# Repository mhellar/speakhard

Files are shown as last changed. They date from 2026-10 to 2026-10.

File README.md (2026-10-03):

# SPEAK//HARD

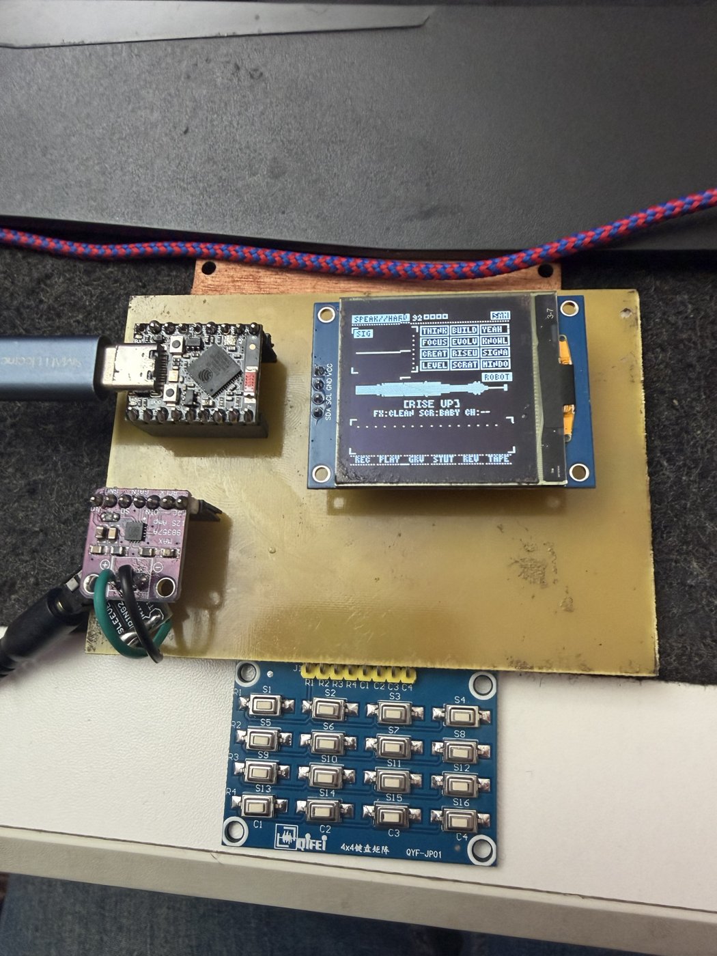
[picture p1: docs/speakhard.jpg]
SPEAK//HARD board


A handheld speech beat machine on an ESP32-S3. Four instruments (SAM voice, Talkie LPC voice, bytebeat, a 12-piece drum kit) on a 16-step sequencer, seven voice FX plus stutter/reverse/tape-stop/scratch, and a live HUD on a 128x128 OLED.

Co-created by Mark Hellar and Claude (Anthropic AI): hardware, design and sound direction by Mark; firmware and PCB layout co-written with Claude. PCB milled and soldered by Mark Hellar.

## Hardware

| Part | Notes |
|---|---|
| ESP32-S3 SuperMini | 4 MB flash, 2 MB PSRAM (PSRAM is required) |
| 1.5" SH1107 128x128 I2C OLED | header order VCC GND SCL SDA |
| MAX98357A I2S amp breakout + small speaker | VIN from 5V |
| 4x4 tact keypad module (QYF-JP01) | passive matrix, mounts on edge pads off the bottom edge |
| Pot module (optional) | edge pads on the right edge; not used by this firmware |

### Pins

| Function | GPIO |
|---|---|
| OLED SDA / SCL | 9 / 8 |
| Keypad rows R1-R4 | 2, 3, 4, 5 |
| Keypad columns C1-C4 | 6, 7, 13, 12 |
| Amp LRC / BCLK / DIN | 1 / 44 / 43 |
| Pot wiper / pot high leg (driven HIGH) | 10 / 11 |

### PCB

Single-sided, all copper on B.Cu, designed for CNC isolation milling on a 100 x 70 mm copper-clad blank. Modules plug into female headers; the keypad and pot modules lie on SMD edge pads with their right-angle pins.

- `hardware/` KiCad 10 project (schematic, PCB, symbol library, `ks_cnc.pretty` footprints)
- `hardware/cnc/` Gerbers (B.Cu, Edge.Cuts), PTH/NPTH drills, a 1:1 fit-test PDF, and ready-made GRBL G-code:
  `1_isolation_0.1vbit.nc` (0.1 mm 20 deg V-bit, Z -0.05) -> `2_holes_1.0drill.nc` -> `3_mounting_2.0drill.nc` -> `4_outline_score_0.1vbit.nc`.
  `load_and_mirror.tcl` regenerates the G-code in FlatCAM (mirrored, since the copper is on the bottom);
  `fix_drill_spinup.py` patches drill files for GRBL laser mode. See `CNC_CHEATSHEET.txt`.

Print `PRINT_1to1_fit_test.pdf` and check your modules against it before milling: the OLED, keypad and pot outlines were measured from photos and typical specs.

## Firmware

`firmware/speakbeat_hard/` is the instrument. `firmware/keypad_bringup/` is a quick test (keys play notes, OLED grid).

Build with the Arduino IDE or arduino-cli:

- ESP32 Arduino core 3.x (tested on 3.3.5)
- Board: ESP32S3 Dev Module, USB CDC On Boot: Enabled, PSRAM: enabled
- Library: U8g2. esp-dsp ships with the ESP32 core.

```
arduino-cli compile --fqbn "esp32:esp32:esp32s3:CDCOnBoot=cdc,PSRAM=enabled" firmware/speakbeat_hard
arduino-cli upload  --fqbn "esp32:esp32:esp32s3:CDCOnBoot=cdc,PSRAM=enabled" -p <port> firmware/speakbeat_hard
```

If the board sits silent after an upload, press RST: on the SuperMini the auto-reset can leave it in the bootloader.

Audio runs at 22.05 kHz in a task on core 0 (it also scans the keypad); the display loop runs on core 1.

## Controls

The left keypad column holds the modifiers; the other 12 keys are pads.

```
[MODE ] [ pad 0 ] [ pad 1 ] [ pad 2 ]
[FX   ] [ pad 3 ] [ pad 4 ] [ pad 5 ]
[SEQ  ] [ pad 6 ] [ pad 7 ] [ pad 8 ]
[SHIFT] [ pad 9 ] [ pad 10] [ pad 11]
```

Tap a modifier for its quick action. Hold it and the screen shows what the 12 pads do while it's held.

| Modifier | Tap | Hold + pad 0..11 |
|---|---|---|
| MODE | next mode | SAM, TALK, BYTE, DRUM, VOL-, VOL+, BANK, voices ROBOT / SAM / ELF / E.T. / BRUTE |
| FX | next FX | CLEAN, CRUSH, ECHO, GRAIN, SWARM, VOX, MEGA, then momentary STUTTER, REVERSE, TAPE, UNDER, and scratch style |
| SEQ | REC on/off | REC, PLAY, GROOVE, AUTO, BPM-, BPM+, MUTATE, CHORDS, CLR VOX, CLR DRM, CLR BYT, CLR ALL |
| SHIFT | PLAY/STOP | per mode, see below |

| Mode | Pads | SHIFT + pad |
|---|---|---|
| SAM | 12 words; tap = say, hold = scratch | scratch the word |
| TALK | 12 LPC words, 4 banks (LIFTOFF, SKY, MATH, PHONETIC); tap = say, hold = scrub the frames | WHISPER, MONO, FREEZE, STRETCH, PITCH-, PITCH+, PITCH 0, GLITCH, BACKWARD, FORMANT-, FORMANT+, RESET |
| BYTE | 12 bytebeat formulas; tap = latch, hold = momentary | RATE/2, RATE*2, A-, A+, B-, B+, SYNC, STOP, CRUSH, REVERSE, RANDOM, RESET |
| DRUM | KICK SNARE CLAP HAT / OPEN 808 ANVIL PIPE / SLAM ZAP CRASH CHUG; tap = hit, hold = roll | mute that drum |

With REC on, everything you play is quantized into the 16 steps. It boots stopped with an empty pattern.

### Sound engine

- SAM words are pre-rendered into PSRAM, so they can be scratched, stuttered and granulated.
- Talkie words are decoded to LPC frames at boot and resynthesized live through the 10-pole lattice filter, so pitch, formant, voicing and coefficients can be bent while it talks.
- VOX is a 16-band vocoder (esp-dsp biquads) with SAM as the modulator and a driven polyBLEP chord carrier. Chord sets: DROP, DREAD, EPIC, MACHINE.
- Drums are synthesized: driven sine kick with a click, metal snare, multi-burst clap, 808-style hats from six detuned square waves, FM clangs, and CHUG, a fuzz power chord that follows the chord progression.
- Kick, 808 and SLAM duck the voices; a soft compressor and a 40 Hz highpass sit on the master.
- `tools/drumsim.py` is a Python port of the drum engine that prints each hit's level; run it after changing the `PERC[]` table.

## Credits

- **SAM** (Software Automatic Mouth, Don't Ask Software, 1982). C port by Sebastian Macke; ESP8266SAM by Earle Philhower.
- **Talkie** by Peter Knight; vocabularies converted by Armin Joachimsmeyer. LPC tables and lattice filter via ESP8266Audio's AudioGeneratorTalkie.
- **esp-dsp** by Espressif.
- **U8g2** by olikraus.
- **Bytebeat** formulas from the viznut (2011) bytebeat scene.

Details in [THIRD_PARTY.md](THIRD_PARTY.md).

## License

GPL v3. See [LICENSE](LICENSE).

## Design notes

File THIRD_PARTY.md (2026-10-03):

# Third-party code

Bundled in `firmware/speakbeat_hard/`:

| Files | Origin | License as stated by the source |
|---|---|---|
| `sam.c`, `render.c`, `reciter.c`, `*Tabs.h`, `SamData.h`, `sam.h`, `render.h`, `reciter.h`, `esp8266sam_debug.*` | SAM, Software Automatic Mouth (Don't Ask Software, 1982), C port by Sebastian Macke (github.com/s-macke/SAM), ESP8266 adaptation by Earle F. Philhower III (github.com/earlephilhower/ESP8266SAM) | ESP8266SAM is distributed under GPL v3. The original 1982 SAM is old commercial software whose copyright status the C port's author describes as unclear. |
| `Vocab_US_Large.*`, `Vocab_AstroBlaster.*`, `Vocab_Soundbites.*`, `Vocab_Toms_Diner.*` | Talkie by Peter Knight (2011), vocabularies converted to .c/.h by Armin Joachimsmeyer (github.com/ArminJo/Talkie) | File headers say "released under GPLv2 license" |
| LPC tables and lattice filter inside `speakbeat_hard.ino` | Talkie by Peter Knight, via ESP8266Audio's AudioGeneratorTalkie (github.com/earlephilhower/ESP8266Audio) | GPL v3 (ESP8266Audio) |

Used as libraries, not bundled:

| Library | Author | License |
|---|---|---|
| U8g2 | olikraus | 2-clause BSD |
| esp-dsp | Espressif | Apache 2.0 |
| arduino-esp32 core (ESP_I2S, Wire) | Espressif | LGPL 2.1 |

The bytebeat formulas are well-known one-liners from the bytebeat scene started by viznut in 2011.

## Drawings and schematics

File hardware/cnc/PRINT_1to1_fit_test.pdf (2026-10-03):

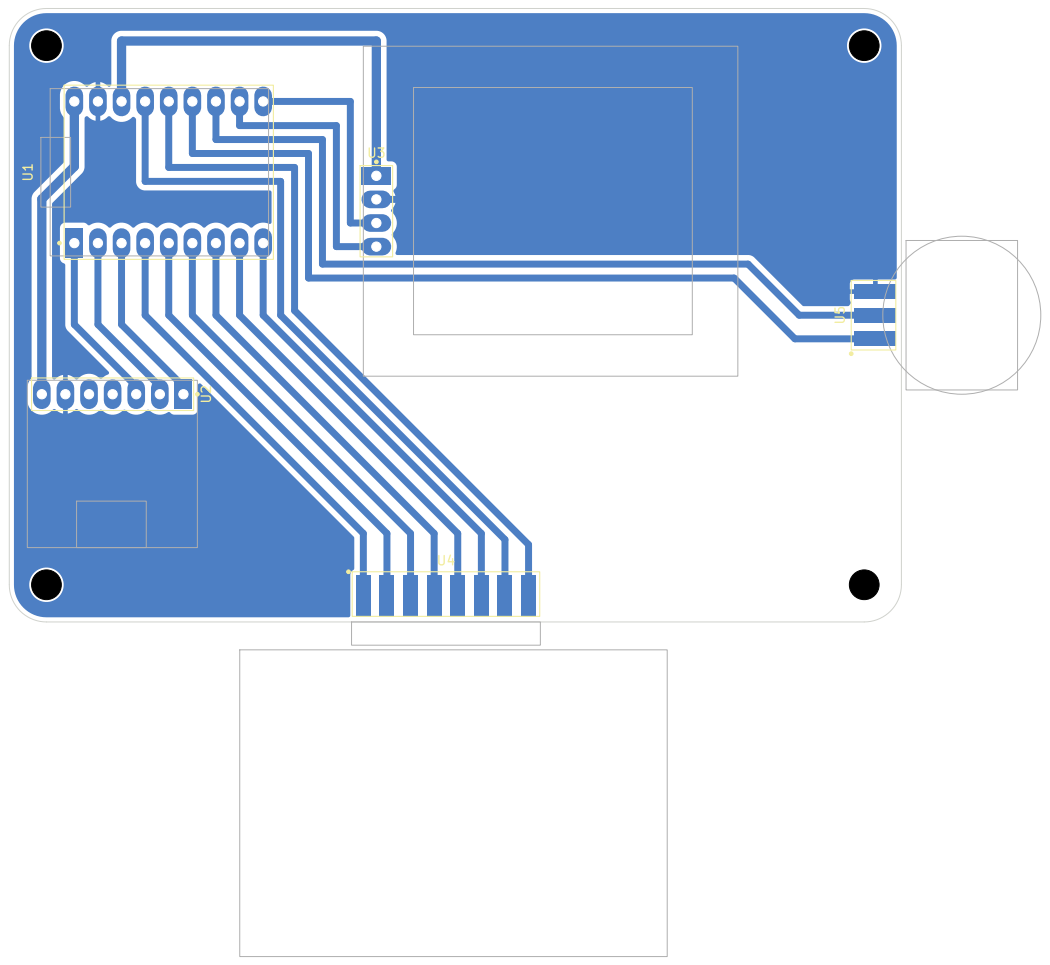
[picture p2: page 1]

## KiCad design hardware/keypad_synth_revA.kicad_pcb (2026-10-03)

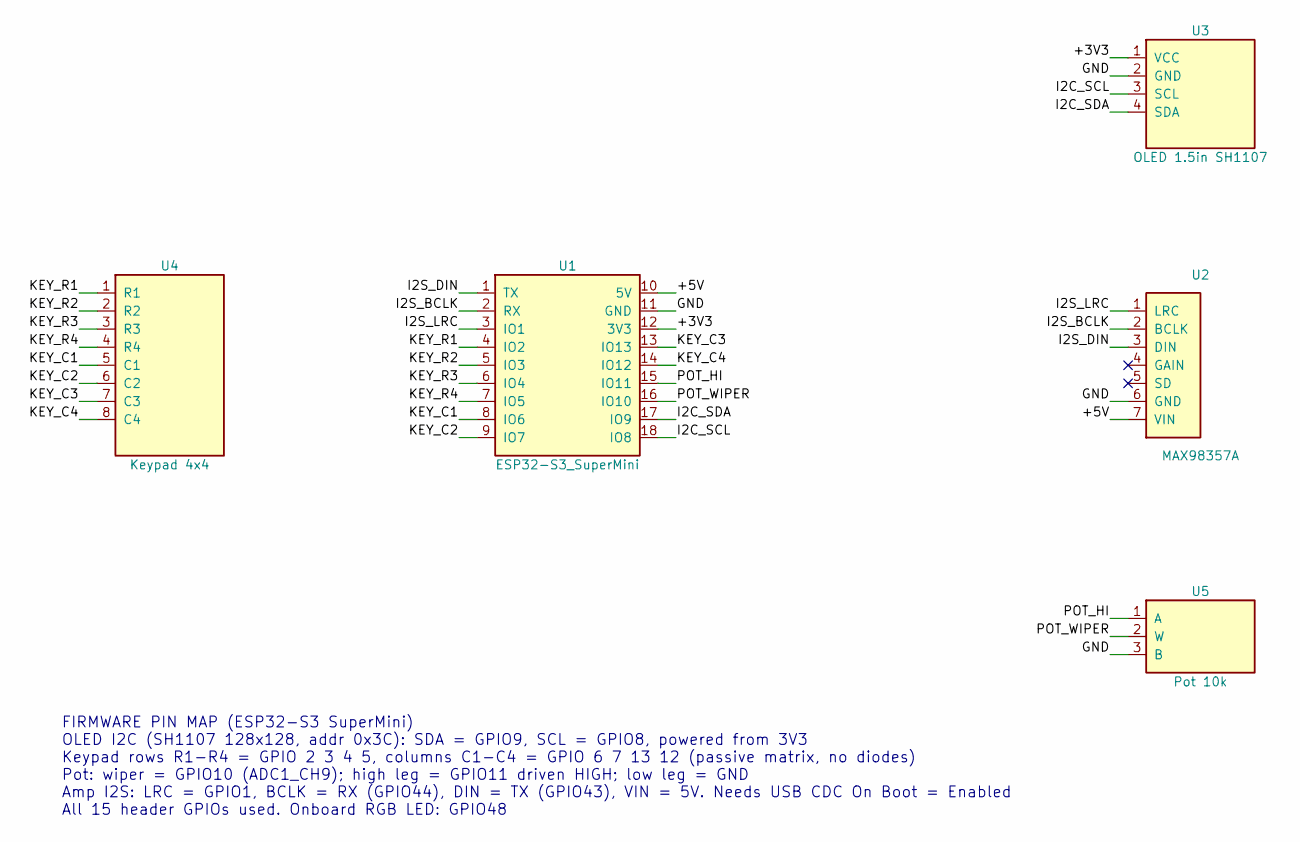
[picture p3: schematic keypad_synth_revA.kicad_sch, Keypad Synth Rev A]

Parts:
U1: ESP32-S3_SuperMini; ESP32-S3_SuperMini_CNC
U2: MAX98357A; MAX98357A_Module_CNC
U3: OLED 1.5in SH1107; OLED_1.5in_128x128_I2C_CNC
U4: Keypad 4x4; EdgePads_Keypad4x4_CNC
U5: Pot 10k; EdgePads_Pot_CNC

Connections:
/+3V3: U1.12 (3V3), U3.1 (VCC)
/+5V: U1.10 (5V), U2.7 (VIN)
/GND: U1.11 (GND), U2.6 (GND), U3.2 (GND), U5.3 (B)
/I2C_SCL: U1.18 (IO8), U3.3 (SCL)
/I2C_SDA: U1.17 (IO9), U3.4 (SDA)
/I2S_BCLK: U1.2 (RX), U2.2 (BCLK)
/I2S_DIN: U1.1 (TX), U2.3 (DIN)
/I2S_LRC: U1.3 (IO1), U2.1 (LRC)
/KEY_C1: U1.8 (IO6), U4.5 (C1)
/KEY_C2: U1.9 (IO7), U4.6 (C2)
/KEY_C3: U1.13 (IO13), U4.7 (C3)
/KEY_C4: U1.14 (IO12), U4.8 (C4)
/KEY_R1: U1.4 (IO2), U4.1 (R1)
/KEY_R2: U1.5 (IO3), U4.2 (R2)
/KEY_R3: U1.6 (IO4), U4.3 (R3)
/KEY_R4: U1.7 (IO5), U4.4 (R4)
/POT_HI: U1.15 (IO11), U5.1 (A)
/POT_WIPER: U1.16 (IO10), U5.2 (W)

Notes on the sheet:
FIRMWARE PIN MAP (ESP32-S3 SuperMini) OLED I2C (SH1107 128x128, addr 0x3C): SDA = GPIO9, SCL = GPIO8, powered from 3V3 Keypad rows R1-R4 = GPIO 2 3 4 5, columns C1-C4 = GPIO 6 7 13 12 (passive matrix, no diodes) Pot: wiper = GPIO10 (ADC1_CH9); high leg = GPIO11 driven HIGH; low leg = GND Amp I2S: L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

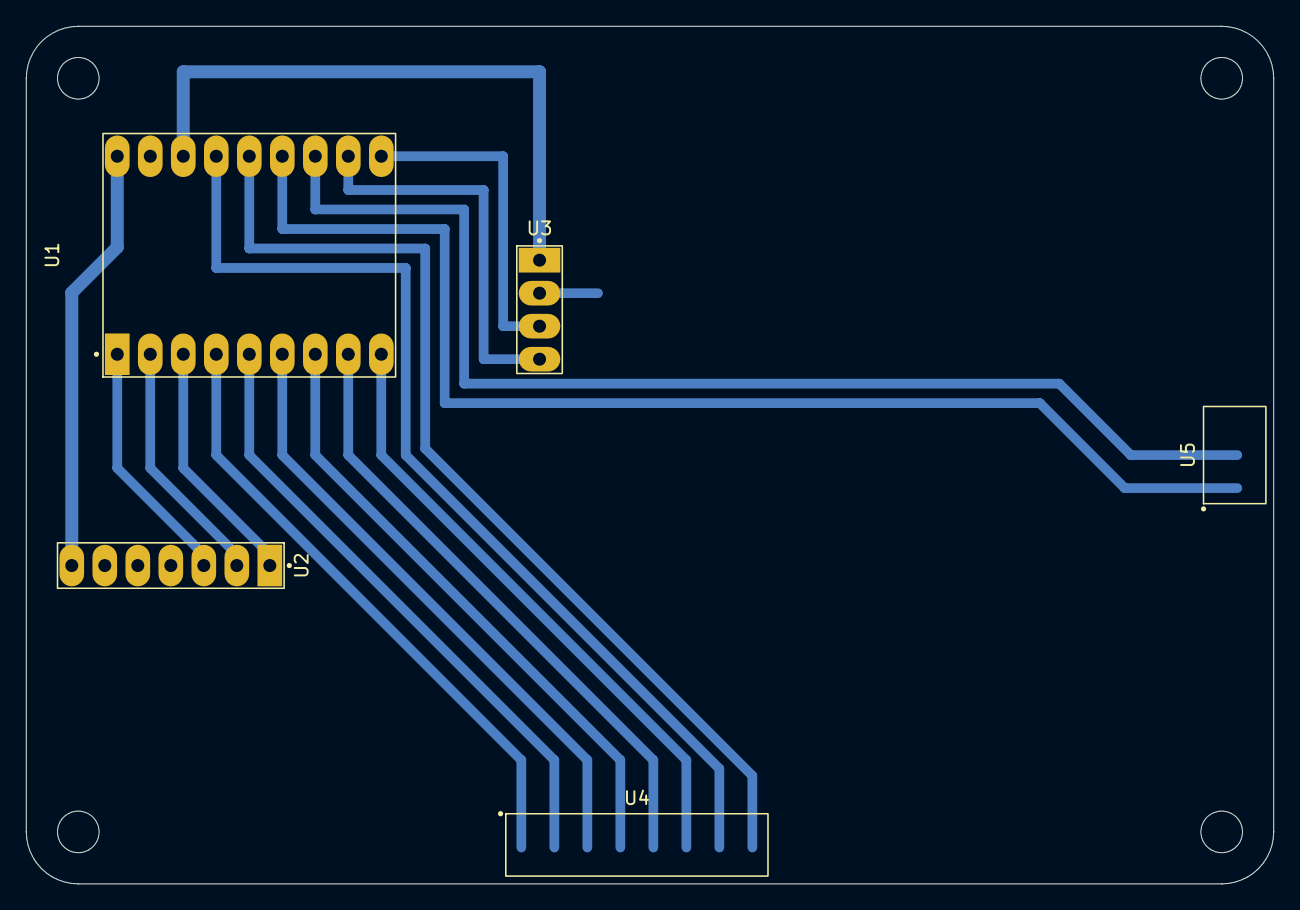
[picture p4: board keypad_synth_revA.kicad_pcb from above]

Board: 2 copper layers, 96.0 x 66.0 mm, 9 parts (0 on the bottom side), 18 nets.

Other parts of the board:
H1, H2, H3, H4: MountingHole_3.2mm_M3

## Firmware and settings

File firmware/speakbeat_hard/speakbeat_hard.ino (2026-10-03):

/*
  SPEAK//HARD - the industrial fork of SPEAK//BEAT (keypad_synth_revA)
  ===========================================================================================================
  Same instrument, harder body: industrial drum kit (driven kick, metal snare, 808-style metal hats, ANVIL/PIPE
  FM clangs, SLAM, 808 sub) plus CHUG, a palm-muted drop-tuned power-chord stab on drum pad 11 that follows the
  chord progression. Kick/808/slam duck the voices (sidechain pump), a soft glue compressor sits on the master,
  MEGA (megaphone voice) replaces CHOIR, the vocoder carrier is driven, progressions are DROP/DREAD/EPIC/MACHINE,
  the BRUTE voice replaces OLD LADY, and the default is 92 BPM. The original speakbeat sketch is untouched.

  Grown out of handheld_robodj (the deck, scratching, voice FX, vocoder and sequencer come from there).
  SAM (Software Automatic Mouth, C core from earlephilhower/ESP8266SAM) and the Talkie LPC vocabularies
  (Peter Knight / Armin Joachimsmeyer) are bundled in this folder; both GPL v3, so this sketch is too.

  KEYPAD (keypad hanging below the board, S1 top-left)
     [MODE ] [ pad 0 ] [ pad 1 ] [ pad 2 ]
     [FX   ] [ pad 3 ] [ pad 4 ] [ pad 5 ]
     [SEQ  ] [ pad 6 ] [ pad 7 ] [ pad 8 ]
     [SHIFT] [ pad 9 ] [ pad 10] [ pad 11]
  Left column: tap for the quick action, HOLD it and the screen shows what the 12 pads do.
     MODE  tap = next mode (SAM > TALK > BYTE > DRUM)      hold: modes, volume, talk bank, SAM voice
     FX    tap = next voice FX                              hold: pick FX, momentary STUTTER/REVERSE/TAPE/UNDER
     SEQ   tap = REC on/off                                 hold: play/stop, groove, auto, BPM, mutate, clears
     SHIFT tap = PLAY/STOP                                  hold: per-mode extras (scratch, LPC bends, bytebeat
                                                                  params, drum mutes)
  Pads by mode:
     SAM   12 positive words. tap = say it, hold = scratch it
     TALK  12 Speak & Spell / arcade LPC words (3 banks). tap = say it, hold = scrub-scratch the LPC frames
     BYTE  12 bytebeat formulas. tap = start/stop (latched), hold = plays only while held
     DRUM  12 drums (KICK SNARE CLAP HAT / OPEN 808 ANVIL PIPE / SLAM ZAP CRASH CHUG). tap = hit, hold = roll
  With REC on, everything you play is quantized into the 16 steps.

  Board: "ESP32S3 Dev Module", USB CDC On Boot: Enabled, PSRAM: enabled
  (arduino-cli FQBN esp32:esp32:esp32s3:CDCOnBoot=cdc,PSRAM=enabled). Libraries: U8g2. ESP32 core 3.x.
*/

#include <Arduino.h>
#include <Wire.h>
#include <U8g2lib.h>
#include <ESP_I2S.h>
#include "esp_dsp.h"
#include "SamData.h"
#include "sam.h"
#include "reciter.h"
#include "Vocab_US_Large.h"
#include "Vocab_AstroBlaster.h"
#include "Vocab_Soundbites.h"
#include "Vocab_Toms_Diner.h"

// ---------------- pins (keypad_synth_revA netlist) ----------------
#define PIN_SDA   9
#define PIN_SCL   8
#define AMP_LRC   1
#define AMP_BCLK  44
#define AMP_DIN   43
#define PIN_RGB   48
const int ROW_PINS[4] = {2, 3, 4, 5};
const int COL_PINS[4] = {6, 7, 13, 12};

#define STATUS_LOG 0      // 1 = print a status line every 2 s (only needed for debugging)
#define FS     22050
#define INV_FS (1.0f / FS)
#define BLOCK  128

const float VOLS[6] = {0.05f, 0.09f, 0.14f, 0.2f, 0.28f, 0.38f};
volatile int volIdx = 2;

// ---------------- types first (Arduino auto-prototypes) ----------------
struct Word { const char* text; uint32_t off, len; };
struct Voice { const char* name; uint8_t speed, pitch, throat, mouth; };
struct Step { int8_t word; uint8_t src, flags; int8_t byteF; uint16_t drum; bool skip; };
struct LpcFrame { uint8_t energy, period; int16_t k1, k2; int8_t k[8]; };
struct TalkWord { const char* name; const uint8_t* data; uint32_t first, n; };
struct PercDef { const char* name; uint8_t wave; float f0, f1, ptime, dec, gain, noise, drive; };
struct ModKey { bool down, used; uint32_t tDown; };

enum { M_SAM, M_TALK, M_BYTE, M_DRUM, M_COUNT };
const char* MODE_NAMES[] = {"SAM", "TALK", "BYTE", "DRUM"};
enum { K_MODE, K_FX, K_SEQ, K_SHIFT };
const char* MOD_NAMES[] = {"MODE", "FX", "SEQ", "SHIFT"};
enum { SRC_SAM, SRC_TALK };
enum { SF_SCRATCH = 1, SF_REV = 2 };
enum { FX_CLEAN, FX_CRUSH, FX_ECHO, FX_GRAIN, FX_SWARM, FX_VOX, FX_MEGA, FX_COUNT };
const char* FX_NAMES[] = {"CLEAN", "CRUSH", "ECHO", "GRAIN", "SWARM", "VOX", "MEGA"};
enum { SC_BABY, SC_CHIRP, SC_TRANS, SC_TEAR, SC_FLARE, SC_COUNT };
const char* SC_NAMES[] = {"BABY", "CHIRP", "TRANSFM", "TEAR", "FLARE"};
#define BYTE_STOP 99

const Voice VOICES[] = {
  {"ROBOT", 92, 60, 190, 190}, {"SAM", 72, 64, 128, 128}, {"ELF", 72, 64, 110, 160},
  {"E.T.", 100, 64, 150, 200}, {"BRUTE", 84, 104, 100, 150},
};
// poetic, positive, short enough to hit like a drum (the last one is the long line to chop up)
Word bank[12] = {
  {"AWAKEN"}, {"STARLIGHT"}, {"YEAH"}, {"BREATHE"}, {"GRAVITY"}, {"INFINITE"},
  {"ECHOES"}, {"WE RISE"}, {"HEARTBEAT"}, {"FREQUENCY"}, {"THUNDER"}, {"WE ARE MADE OF STARS"},
};

#define NBANKS 4
TalkWord talk[NBANKS][12] = {
  {{"READY", sp4_READY}, {"GO", sp2_GO}, {"IGNITE", sp5_IGNITE}, {"LAUNCH", sp5_LAUNCH},
   {"BOOST", sp5_BOOST}, {"POWER", sp2_POWER}, {"ACTION", sp4_ACTION}, {"CONNECT", sp2_CONNECT},
   {"GREAT", sp4_GREAT}, {"UNLIMITED", sp3_UNLIMITED}, {"FREEDOM", sp5_FREEDOM}, {"ONE SMALL STEP", spONE_SMALL_STEP}},
  {{"LIGHT", sp4_LIGHT}, {"RAIN", sp3_RAIN}, {"WIND", sp3_WIND}, {"SNOW", sp3_SNOW},
   {"MIST", sp3_MIST}, {"CALM", sp5_CALM}, {"GLIDE", sp4_GLIDE}, {"ALOFT", sp3_ALOFT},
   {"HIGH", sp3_HIGH}, {"CLEAR", sp3_CLEAR}, {"TRUE", sp4_TRUE}, {"GREEN", sp3_GREEN}},
  {{"ONE", sp3_ONE}, {"TWO", sp3_TWO}, {"THREE", sp3_THREE}, {"FOUR", sp3_FOUR},
   {"FIVE", sp3_FIVE}, {"SIX", sp3_SIX}, {"SEVEN", sp3_SEVEN}, {"EIGHT", sp3_EIGHT},
   {"PLUS", sp3_PLUS}, {"EQUALS", sp3_EQUALS}, {"MILLION", sp3_MILLION}, {"TOM'S DINER", spDINER}},
  {{"ALPHA", sp4_ALPHA}, {"BRAVO", sp4_BRAVO}, {"CHARLIE", sp4_CHARLIE}, {"DELTA", sp4_DELTA},
   {"ECHO", sp4_ECHO}, {"FOXTROT", sp4_FOXTROT}, {"TANGO", sp4_TANGO}, {"ZULU", sp4_ZULU},
   {"ROGER", sp4_ROGER}, {"AFFIRMATIVE", sp4_AFFIRMATIVE}, {"OPERATIONAL", operational}, {"HMMM BEER", spHMMM_BEER}},
};
const char* BANK_NAMES[NBANKS] = {"LIFTOFF", "SKY", "MATH", "PHONETIC"};

// industrial kit. drive > 0 = the hit goes through softclip after its envelope (hits harder, not fizzier).
// W_METAL: f0 scales the six 808 cymbal squares. W_FM: f0 carrier, f1 modulator ratio, noise = FM index.
// W_CHUG: power chord on chugHz (follows the chord progression), f0 unused.
// Levels balanced offline (drumsim.py port of this engine, 100 ms RMS): kick/snare ~-9 dB audible, hats ~-21.
enum { W_SINE, W_KICK, W_SNR, W_CLAP, W_METAL, W_FM, W_SLAM, W_CHUG };
const PercDef PERC[12] = {
  // name     wave     f0     f1     ptime   dec    gain   noise  drive
  {"KICK",  W_KICK,  190,   52,    0.045f, 0.40f, 0.95f, 0.6f,  2.2f},
  {"SNARE", W_SNR,   210,   165,   0.025f, 0.20f, 0.62f, 0.9f,  2.0f},
  {"CLAP",  W_CLAP,  0,     0,     0.01f,  0.16f, 0.72f, 0,     1.6f},
  {"HAT",   W_METAL, 1.6f,  0,     0.01f,  0.035f,0.67f, 0,     0},
  {"OPEN",  W_METAL, 1.6f,  0,     0.01f,  0.28f, 0.60f, 0,     0},
  {"808",   W_KICK,  110,   50,    0.09f,  1.00f, 0.85f, 0.2f,  1.7f},
  {"ANVIL", W_FM,    380,   2.76f, 0.06f,  0.55f, 0.40f, 1.8f,  0},
  {"PIPE",  W_FM,    520,   1.41f, 0.12f,  0.32f, 0.40f, 0.7f,  0},
  {"SLAM",  W_SLAM,  90,    48,    0.05f,  0.26f, 0.72f, 0,     3.0f},
  {"ZAP",   W_SINE,  2600,  70,    0.025f, 0.18f, 0.55f, 0,     0},
  {"CRASH", W_METAL, 1.0f,  0,     0.01f,  1.10f, 0.58f, 0,     0},
  {"CHUG",  W_CHUG,  0,     0,     0.05f,  0.20f, 0.55f, 0,     0},
};
enum { D_KICK, D_SNARE, D_CLAP, D_HAT, D_OPEN, D_808, D_ANVIL, D_PIPE, D_SLAM, D_ZAP, D_CRASH, D_CHUG };
const uint16_t DUCK_MASK = (1 << D_KICK) | (1 << D_808) | (1 << D_SLAM);

const char* BYTE_NAMES[12] = {"SIERPINSKI", "CRYSTAL", "FORTY-TWO", "VIZNUT", "STAIRS", "CHIP ARP",
                              "SKURK", "XPANSIVE", "VISY", "NOISEWALL", "TANGLE", "TEJEEZ"};
const int8_t BYTE_A[12] = {8, 5, 10, 7, 8, 9, 6, 8, 9, 10, 9, 8};
const int8_t BYTE_B[12] = {8, 8, 8, 10, 8, 8, 16, 9, 13, 15, 7, 11};

// Serial log that never blocks: with USB plugged in but no serial monitor open, the USB-CDC TX buffer fills
// and a plain Serial.printf hangs (screen froze ~3 s after boot, audio task stalled). Lines that don't fit are dropped.
void logf(const char* fmt, ...) {
  char b[160];
  va_list ap; va_start(ap, fmt);
  int n = vsnprintf(b, sizeof b, fmt, ap);
  va_end(ap);
  if (n <= 0) return;
  n = min(n, (int)sizeof b - 1);
  if (Serial.availableForWrite() >= n) Serial.write((const uint8_t*)b, n);
}

U8G2_SH1107_PIMORONI_128X128_F_HW_I2C oled(U8G2_R1, U8X8_PIN_NONE, PIN_SCL, PIN_SDA);   // R1 = 90 deg clockwise
I2SClass amp;

void drawFrame();

// =====================================================================
// SAM -> sample pool (from Robo DJ)
// =====================================================================
SamData* samdata;
int8_t* pool = nullptr;
uint32_t poolSize = 0, poolPos = 0;
volatile bool bankBusy = true;
volatile int voiceIdx = 0;
int renderProgress = 0;

static void samByte(void*, unsigned char b) { if (poolPos < poolSize) pool[poolPos++] = (int8_t)((int)b - 128); }

bool sayToPool(const char* text, const Voice& v) {
  char input[256];
  int n = 0;
  for (; text[n] && n < 200; n++) input[n] = toupper((int)text[n]);
  input[n] = 0;
  strcat(input, "[");
  samdata = new SamData;
  if (!samdata) return false;
  EnableSingmode(0);
  SetSpeed(v.speed); SetPitch(v.pitch); SetThroat(v.throat); SetMouth(v.mouth);
  bool ok = TextToPhonemes(input);
  if (ok) { SetInput(input); SAMMain(samByte, nullptr); }
  delete samdata;
  return ok;
}

void renderBank(int vi) {
  bankBusy = true;
  delay(30);
  poolPos = 0;
  for (int i = 0; i < 12; i++) {
    renderProgress = i;
    drawFrame();
    uint32_t start = poolPos;
    bank[i].off = start; bank[i].len = 0;
    if (poolSize - poolPos < FS / 2) continue;
    if (!sayToPool(bank[i].text, VOICES[vi])) { poolPos = start; continue; }
    uint32_t a = start, b = poolPos;
    while (a < b && abs(pool[a]) < 4) a++;
    while (b > a && abs(pool[b - 1]) < 4) b--;
    bank[i].off = a; bank[i].len = b > a + 8 ? b - a : 0;
  }
  renderProgress = 12;
  logf("SAM voice %s: %u bytes\n", VOICES[vi].name, poolPos);
  bankBusy = false;
}

static inline float wordAt(int w, float p) {
  const Word& wd = bank[w];
  if (p < 0 || p >= (float)wd.len - 1) return 0;          // float compare: len 0 must not wrap to 4 billion
  int i = (int)p; float f = p - i;
  float a = pool[wd.off + i], b = pool[wd.off + i + 1];
  return (a + (b - a) * f) * (1.0f / 128.0f);
}

// =====================================================================
// Talkie LPC: words decoded to frames at boot, re-synthesized live (so they can be bent)
// Tables and lattice filter from Talkie (Peter Knight) via ESP8266Audio's AudioGeneratorTalkie.
// =====================================================================
#pragma GCC diagnostic push
#pragma GCC diagnostic ignored "-Wnarrowing"
static const uint8_t tmsEnergy[0x10] = {0x00,0x02,0x03,0x04,0x05,0x07,0x0a,0x0f,0x14,0x20,0x29,0x39,0x51,0x72,0xa1,0xff};
static const uint8_t tmsPeriod[0x40] = {0x00,0x10,0x11,0x12,0x13,0x14,0x15,0x16,0x17,0x18,0x19,0x1A,0x1B,0x1C,0x1D,0x1E,0x1F,0x20,0x21,0x22,0x23,0x24,0x25,0x26,0x27,0x28,0x29,0x2A,0x2B,0x2D,0x2F,0x31,0x33,0x35,0x36,0x39,0x3B,0x3D,0x3F,0x42,0x45,0x47,0x49,0x4D,0x4F,0x51,0x55,0x57,0x5C,0x5F,0x63,0x66,0x6A,0x6E,0x73,0x77,0x7B,0x80,0x85,0x8A,0x8F,0x95,0x9A,0xA0};
static const int16_t tmsK1[0x20] = {0x82C0,0x8380,0x83C0,0x8440,0x84C0,0x8540,0x8600,0x8780,0x8880,0x8980,0x8AC0,0x8C00,0x8D40,0x8F00,0x90C0,0x92C0,0x9900,0xA140,0xAB80,0xB840,0xC740,0xD8C0,0xEBC0,0x0000,0x1440,0x2740,0x38C0,0x47C0,0x5480,0x5EC0,0x6700,0x6D40};
static const int16_t tmsK2[0x20] = {0xAE00,0xB480,0xBB80,0xC340,0xCB80,0xD440,0xDDC0,0xE780,0xF180,0xFBC0,0x0600,0x1040,0x1A40,0x2400,0x2D40,0x3600,0x3E40,0x45C0,0x4CC0,0x5300,0x5880,0x5DC0,0x6240,0x6640,0x69C0,0x6CC0,0x6F80,0x71C0,0x73C0,0x7580,0x7700,0x7E80};
static const int8_t tmsK3[0x10] = {0x92,0x9F,0xAD,0xBA,0xC8,0xD5,0xE3,0xF0,0xFE,0x0B,0x19,0x26,0x34,0x41,0x4F,0x5C};
static const int8_t tmsK4[0x10] = {0xAE,0xBC,0xCA,0xD8,0xE6,0xF4,0x01,0x0F,0x1D,0x2B,0x39,0x47,0x55,0x63,0x71,0x7E};
static const int8_t tmsK5[0x10] = {0xAE,0xBA,0xC5,0xD1,0xDD,0xE8,0xF4,0xFF,0x0B,0x17,0x22,0x2E,0x39,0x45,0x51,0x5C};
static const int8_t tmsK6[0x10] = {0xC0,0xCB,0xD6,0xE1,0xEC,0xF7,0x03,0x0E,0x19,0x24,0x2F,0x3A,0x45,0x50,0x5B,0x66};
static const int8_t tmsK7[0x10] = {0xB3,0xBF,0xCB,0xD7,0xE3,0xEF,0xFB,0x07,0x13,0x1F,0x2B,0x37,0x43,0x4F,0x5A,0x66};
static const int8_t tmsK8[0x08] = {0xC0,0xD8,0xF0,0x07,0x1F,0x37,0x4F,0x66};
static const int8_t tmsK9[0x08] = {0xC0,0xD4,0xE8,0xFC,0x10,0x25,0x39,0x4D};
static const int8_t tmsK10[0x08] = {0xCD,0xDF,0xF1,0x04,0x16,0x20,0x3B,0x4D};
static const int8_t chirp[] = {0x00,0x2a,0xd4,0x32,0xb2,0x12,0x25,0x14,0x02,0xe1,0xc5,0x02,0x5f,0x5a,0x05,0x0f,0x26,0xfc,0xa5,0xa5,0xd6,0xdd,0xdc,0xfc,0x25,0x2b,0x22,0x21,0x0f,0xff,0xf8,0xee,0xed,0xef,0xf7,0xf6,0xfa,0x00,0x03,0x02,0x01};
#pragma GCC diagnostic pop

LpcFrame* lpcFrames = nullptr;
uint32_t lpcCap = 0, lpcUsed = 0;
volatile int talkBank = 0;

struct BitReader {
  const uint8_t* p; uint8_t bit = 0;
  static uint8_t rev(uint8_t a) {
    a = (a >> 4) | (a << 4); a = ((a & 0xcc) >> 2) | ((a & 0x33) << 2); a = ((a & 0xaa) >> 1) | ((a & 0x55) << 1); return a;
  }
  uint8_t get(uint8_t bits) {
    uint16_t data = rev(p[0]) << 8;
    if (bit + bits > 8) data |= rev(p[1]);
    data <<= bit;
    uint8_t v = data >> (16 - bits);
    bit += bits;
    if (bit >= 8) { bit -= 8; p++; }
    return v;
  }
};

// decode one LPC word; out == nullptr just counts frames
uint32_t decodeLpc(const uint8_t* data, LpcFrame* out, uint32_t maxN) {
  BitReader br{data};
  LpcFrame cur = {};
  uint32_t n = 0;
  while (n < maxN) {
    uint8_t e = br.get(4);
    if (e == 0xF) break;
    if (e == 0) cur.energy = 0;
    else {
      cur.energy = tmsEnergy[e];
      uint8_t rep = br.get(1);
      cur.period = tmsPeriod[br.get(6)];
      if (!rep) {
        cur.k1 = tmsK1[br.get(5)]; cur.k2 = tmsK2[br.get(5)];
        cur.k[0] = tmsK3[br.get(4)]; cur.k[1] = tmsK4[br.get(4)];
        if (cur.period) {
          cur.k[2] = tmsK5[br.get(4)]; cur.k[3] = tmsK6[br.get(4)]; cur.k[4] = tmsK7[br.get(4)];
          cur.k[5] = tmsK8[br.get(3)]; cur.k[6] = tmsK9[br.get(3)]; cur.k[7] = tmsK10[br.get(3)];
        }
      }
    }
    if (out) out[n] = cur;
    n++;
  }
  return n;
}

void decodeTalk() {
  const uint32_t MAXW = 8000;                       // ~200 s per word, plenty (Tom's Diner is the long one)
  uint32_t total = 0;
  for (auto& b : talk) for (auto& w : b) total += decodeLpc(w.data, nullptr, MAXW);
  lpcCap = total;
  lpcFrames = psramFound() ? (LpcFrame*)ps_malloc(total * sizeof(LpcFrame)) : nullptr;
  if (!lpcFrames) lpcFrames = (LpcFrame*)malloc(total * sizeof(LpcFrame));
  if (!lpcFrames) { logf("!! no memory for LPC frames\n"); return; }
  for (auto& b : talk) for (auto& w : b) {
    uint32_t n = decodeLpc(w.data, lpcFrames + lpcUsed, MAXW);
    uint32_t a = 0;
    while (a < n && lpcFrames[lpcUsed + a].energy == 0) a++;      // trim silent frames at both ends
    while (n > a && lpcFrames[lpcUsed + n - 1].energy == 0) n--;
    w.first = lpcUsed + a; w.n = n - a;
    lpcUsed += n;
  }
  logf("LPC: %u frames decoded (%u KB)\n", lpcUsed, lpcUsed * sizeof(LpcFrame) / 1024);
}

// live LPC voice with circuit bends
volatile bool lpWhisper = false, lpMono = false, lpFreeze = false, lpStretch = false, lpGlitch = false, lpRev = false;
volatile float lpPitch = 1, lpFormant = 1;
volatile float monoFreq = 130;

struct Lpc {
  int bank = 0, word = -1; float fpos = 0; bool on = false, scratch = false, rev = false; float base = 0;
  int loaded = -1;
  uint8_t period = 0; int32_t energy = 0, k1 = 0, k2 = 0; int32_t k[8] = {0};
  uint8_t pc = 0; int32_t x[10] = {0}; uint16_t rnd = 1;
  float ph = 0, y0 = 0, y1 = 0;
} lpc;
volatile int lpcVisFrame = -1;

void talkPlay(int w, bool rev) {
  const TalkWord& t = talk[talkBank][w];
  if (!t.n) return;
  lpc.bank = talkBank; lpc.word = w; lpc.rev = rev ^ lpRev; lpc.scratch = false;
  lpc.fpos = lpc.rev ? t.n - 0.01f : 0; lpc.loaded = -1; lpc.on = true;
}
void talkScratch(int w) {
  const TalkWord& t = talk[talkBank][w];
  if (!t.n) return;
  lpc.bank = talkBank; lpc.word = w; lpc.scratch = true; lpc.base = 0; lpc.fpos = 0; lpc.loaded = -1; lpc.on = true;
}

void lpcLoad(int fi) {
  const TalkWord& t = talk[lpc.bank][lpc.word];
  const LpcFrame& f = lpcFrames[t.first + fi];
  lpc.loaded = fi;
  lpc.energy = f.energy;
  lpc.k1 = f.k1; lpc.k2 = f.k2;
  for (int i = 0; i < 8; i++) lpc.k[i] = f.k[i];
  if (lpGlitch) {                                   // circuit bend: corrupt some coefficients
    if (random(3) == 0) lpc.k1 = tmsK1[random(32)];
    if (random(3) == 0) lpc.k2 = tmsK2[random(32)];
    if (random(2) == 0) lpc.k[random(8)] = -lpc.k[random(8)];
  }
  int per = f.period;
  if (lpWhisper) per = 0;
  else if (per) {
    if (lpMono) per = (int)(8000.0f / monoFreq);
    else per = (int)(per / lpPitch);
    per = constrain(per, 10, 255);
  }
  lpc.period = per;
}

// one 8 kHz sample
static inline float lpcTick() {
  const TalkWord& t = talk[lpc.bank][lpc.word];
  if (!lpc.on || !t.n) return 0;
  int fi = (int)lpc.fpos;
  if (fi < 0 || fi >= (int)t.n) { if (!lpc.scratch) { lpc.on = false; return 0; } fi = constrain(fi, 0, (int)t.n - 1); }
  if (fi != lpc.loaded) lpcLoad(fi);
  if (!lpc.scratch && !lpFreeze) lpc.fpos += (lpc.rev ? -1.0f : 1.0f) * (lpStretch ? 0.4f : 1.0f) / 200.0f;

  int32_t u10;
  if (lpc.period) {
    if (lpc.pc < lpc.period) lpc.pc++; else lpc.pc = 0;
    u10 = lpc.pc < sizeof(chirp) ? (chirp[lpc.pc] * lpc.energy) >> 8 : 0;
  } else {
    lpc.rnd = (lpc.rnd >> 1) ^ ((lpc.rnd & 1) ? 0xB800 : 0);
    u10 = (lpc.rnd & 1) ? lpc.energy : -lpc.energy;
  }
  int32_t* x = lpc.x; int32_t* k = lpc.k;
  int32_t u9 = u10 - ((k[7] * x[9]) >> 7);
  int32_t u8 = u9 - ((k[6] * x[8]) >> 7);
  int32_t u7 = u8 - ((k[5] * x[7]) >> 7);
  int32_t u6 = u7 - ((k[4] * x[6]) >> 7);
  int32_t u5 = u6 - ((k[3] * x[5]) >> 7);
  int32_t u4 = u5 - ((k[2] * x[4]) >> 7);
  int32_t u3 = u4 - ((k[1] * x[3]) >> 7);
  int32_t u2 = u3 - ((k[0] * x[2]) >> 7);
  int32_t u1 = u2 - ((lpc.k2 * x[1]) >> 15);
  int32_t u0 = u1 - ((lpc.k1 * x[0]) >> 15);
  u0 = constrain(u0, -512, 511);
  x[9] = x[8] + ((k[6] * u8) >> 7);
  x[8] = x[7] + ((k[5] * u7) >> 7);
  x[7] = x[6] + ((k[4] * u6) >> 7);
  x[6] = x[5] + ((k[3] * u5) >> 7);
  x[5] = x[4] + ((k[2] * u4) >> 7);
  x[4] = x[3] + ((k[1] * u3) >> 7);
  x[3] = x[2] + ((k[0] * u2) >> 7);
  x[2] = x[1] + ((lpc.k2 * u1) >> 15);
  x[1] = x[0] + ((lpc.k1 * u0) >> 15);
  x[0] = u0;
  for (int i = 0; i < 10; i++) x[i] = constrain(x[i], -32768, 32767);
  return u0 * (1.0f / 512.0f);
}

// =====================================================================
// Bytebeat
// =====================================================================
struct ByteBeat {
  bool on = false; int f = 0; uint32_t t = 0; float acc = 0; float rate = 1; int a = 8, b = 8;
  bool sync = true, crush = false, rev = false; uint8_t cur = 128;
} bb;
volatile uint8_t byteVis[128];

static inline uint32_t sh(uint32_t v, int s) { return v >> (s & 31); }
static inline uint8_t byteFormula(int f, uint32_t t, int a, int b) {
  switch (f) {
    case 0: return t & sh(t, a);
    case 1: return t * (sh(t, a) | sh(t, b));
    case 2: return t * (42 & sh(t, a));
    case 3: return (t * 5 & sh(t, a)) | (t * 3 & sh(t, b));
    case 4: return t * ((t >> 12 | sh(t, a)) & 63 & t >> 4);
    case 5: return (t * (0xCA98 >> (sh(t, a) & 14) & 15)) | sh(t, b);
    case 6: return (sh(t, a) | t | sh(t, (t >> b) & 31)) * 10 + ((t >> 11) & 7);
    case 7: return ((t * (sh(t, a) | t >> 9) & 46 & sh(t, a)) ^ (t & t >> 13 | t >> 6));
    case 8: return t * ((sh(t, a) | sh(t, b)) & 25 & t >> 6);
    case 9: return t * (t ^ (t + (sh(t, b) | 1)) ^ sh(t - 1280 ^ t, a));
    case 10: return (t | (sh(t, a) | t >> 7)) * t & (t >> 11 | sh(t, a));
    default: return t * (t >> 11 & sh(t, a)) & 123 & t >> 3;
  }
}
void byteStart(int f) {
  if (bb.f != f || !bb.on) { bb.a = BYTE_A[f]; bb.b = BYTE_B[f]; }
  bb.f = f; bb.t = 0; bb.on = true;
}
void byteStop() { bb.on = false; }

// =====================================================================
// DSP helpers + drums
// =====================================================================
float sineTab[1025];
static inline float wrap1(float p) { return p - floorf(p); }
static inline float fsin(float ph) {
  float x = ph * 1024.0f; int i = (int)x; float f = x - i; i &= 1023;
  return sineTab[i] + (sineTab[i + 1] - sineTab[i]) * f;
}
static uint32_t nstate = 22222;
static inline float nz() { nstate ^= nstate << 13; nstate ^= nstate >> 17; nstate ^= nstate << 5; return (int32_t)nstate * (1.0f / 2147483648.0f); }
static inline float dcoef(float sec) { return expf(-1.0f / (sec * FS)); }
static inline float softclip(float x) { if (x > 3) return 1; if (x < -3) return -1; return x * (27 + x * x) / (27 + 9 * x * x); }

volatile float chugHz = 73.4f;                       // set by vocChord(): drop-D-ish root of the current chord
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
void loop() {
  static int renderedVoice = 0;
  if (voiceIdx != renderedVoice) {
    renderedVoice = voiceIdx;
    renderBank(renderedVoice);
    flash(VOICES[renderedVoice].name);
    deckPlay(curPad, false);
  }
  drawFrame();
  static uint32_t lastLog = 0;
  if (STATUS_LOG && millis() - lastLog > 2000) {
    lastLog = millis();
    logf("t=%lus mode %s fx %s step %d blocks %lu heap %u stackfree %u keys %04X\n", millis() / 1000,
         MODE_NAMES[mode], FX_NAMES[fx], curStep, (unsigned long)audioBlocks, (unsigned)ESP.getFreeHeap(),
         audioHandle ? (unsigned)uxTaskGetStackHighWaterMark(audioHandle) : 0u, keysRaw);
  }
  delay(5);
}

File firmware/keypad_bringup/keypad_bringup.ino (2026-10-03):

// Keypad Synth Rev A - bench bring-up test (ESP32-S3 SuperMini)
// Board: "ESP32S3 Dev Module", Tools > USB CDC On Boot: "Enabled" (REQUIRED - TX/RX are used for the amp),
// Serial Monitor 115200. Library: U8g2.
//
// On boot: I2C scan (OLED should answer at 0x3C), then a 0.3 s beep through the amp.
// Keypad: each of the 16 keys plays a note (C major pentatonic, S1 = lowest) while held.
// Pot: volume. OLED shows the 4x4 key grid, the pot level and the last key.
// Serial prints every key press/release and the pot value every 500 ms.
// If a key lights up the wrong square, the R/C wiring is swapped - check the edge pads for solder bridges first.

#include <Arduino.h>
#include <Wire.h>
#include <U8g2lib.h>
#include <ESP_I2S.h>
#include <math.h>
#include <esp_system.h>

// Pins - straight from the KiCad netlist (keypad_synth_revA)
const int PIN_SDA = 9, PIN_SCL = 8;
const int ROW_PINS[4] = {2, 3, 4, 5};      // R1..R4 (driven LOW one at a time)
const int COL_PINS[4] = {6, 7, 13, 12};    // C1..C4 (INPUT_PULLUP)
const int PIN_POT = 10, PIN_POT_HI = 11;   // wiper on ADC1_CH9; GPIO11 powers the pot's high leg
const int PIN_AMP_LRC = 1, PIN_AMP_BCLK = 44, PIN_AMP_DIN = 43;   // BCLK = RX, DIN = TX
const int PIN_RGB = 48;
const bool POT_INSTALLED = false;     // pot removed for now (10-02): fixed volume, ignore the floating ADC pin

// GME128128-01-IIC needs the PIMORONI variant (the generic one wraps the picture by 32 px)
U8G2_SH1107_PIMORONI_128X128_F_HW_I2C oled(U8G2_R1,   // R1 = rotated 90 deg clockwise
                                           U8X8_PIN_NONE, PIN_SCL, PIN_SDA);
bool oledOk = false;

I2SClass amp;
const int RATE = 32000, BLOCK = 256;
volatile int noteKey = -1;       // key currently sounding (-1 = none)
volatile float volume = 0.1f;
volatile uint32_t audioBlocks = 0;   // climbs ~125/s while the audio task is alive
const char *resetWhy = "?";
const int SCALE[5] = {0, 2, 4, 7, 9};

float keyFreq(int k) {           // 16 keys over ~3 octaves of C pentatonic from C4
  int semis = SCALE[k % 5] + 12 * (k / 5);
  return 261.63f * powf(2.0f, semis / 12.0f);
}

void audioTask(void *) {
  static int16_t buf[BLOCK * 2];
  float phase = 0, env = 0;
  for (;;) {
    int k = noteKey;
    float step = (k >= 0 ? keyFreq(k) : 0) / RATE;
    for (int i = 0; i < BLOCK; i++) {
      env += ((k >= 0 ? 1.0f : 0.0f) - env) * 0.002f;          // soft attack/release, no clicks
      phase += step; if (phase >= 1) phase -= 1;
      float tri = 4 * fabsf(phase - 0.5f) - 1;                   // triangle wave
      int16_t s = (int16_t)(tri * env * volume * 32767);
      buf[i * 2] = s; buf[i * 2 + 1] = s;
    }
    amp.write((uint8_t *)buf, sizeof(buf));
    audioBlocks++;
  }
}

void i2cScan() {
  Wire.begin(PIN_SDA, PIN_SCL);
  Serial.print("I2C scan (SDA 9, SCL 8):");
  int found = 0;
  for (uint8_t a = 1; a < 127; a++) {
    Wire.beginTransmission(a);
    if (Wire.endTransmission() == 0) { Serial.printf(" 0x%02X", a); found++; if (a == 0x3C || a == 0x3D) oledOk = true; }
  }
  Serial.println(found ? "" : " nothing found - check OLED VCC/GND/SDA/SCL");
}

// Scan the passive matrix: one row LOW at a time, the other rows floating (INPUT) so two held keys can't short rows.
uint16_t scanKeys() {
  uint16_t bits = 0;
  for (int r = 0; r < 4; r++) {
    pinMode(ROW_PINS[r], OUTPUT);
    digitalWrite(ROW_PINS[r], LOW);
    delayMicroseconds(30);
    for (int c = 0; c < 4; c++)
      if (!digitalRead(COL_PINS[c])) bits |= 1 << (r * 4 + c);
    pinMode(ROW_PINS[r], INPUT);
  }
  return bits;
}

void drawOled(uint16_t keys, int pot, int last) {
  oled.clearBuffer();
  oled.setFont(u8g2_font_6x10_tf);
  oled.drawStr(0, 9, "Keypad Synth revA");
  for (int k = 0; k < 16; k++) {
    int x = 4 + (k % 4) * 22, y = 16 + (k / 4) * 22;
    if (keys & (1 << k)) oled.drawBox(x, y, 18, 18); else oled.drawFrame(x, y, 18, 18);
  }
  oled.drawFrame(100, 16, 20, 84);                                // pot bar
  int h = pot * 82 / 4095; oled.drawBox(101, 99 - h, 18, h);
  char line[24];
  snprintf(line, sizeof line, "pot %4d", pot); oled.drawStr(0, 114, line);
  if (last >= 0) { snprintf(line, sizeof line, "S%d", last + 1); oled.drawStr(64, 114, line); }
  static uint8_t spin = 0; const char *sp = "|/-\\";
  snprintf(line, sizeof line, "up %lus %c %s", millis() / 1000, sp[spin++ & 3], resetWhy); oled.drawStr(0, 126, line);
  oled.sendBuffer();
}

const char *resetReason() {
  switch (esp_reset_reason()) {
    case ESP_RST_POWERON: return "POWERON";
    case ESP_RST_SW: return "SW";
    case ESP_RST_PANIC: return "PANIC";
    case ESP_RST_INT_WDT: return "INT_WDT";
    case ESP_RST_TASK_WDT: return "TASK_WDT";
    case ESP_RST_WDT: return "WDT";
    case ESP_RST_BROWNOUT: return "BROWNOUT";
    case ESP_RST_USB: return "USB";
    case ESP_RST_EXT: return "EXT";
    default: return "OTHER";
  }
}

void setup() {
  Serial.setTxTimeoutMs(0);   // never block when the USB host isn't reading
  Serial.begin(115200);
  delay(1500);
  resetWhy = resetReason();
  Serial.printf("\n=== Keypad Synth Rev A bring-up === last reset: %s\n", resetWhy);
  for (int c = 0; c < 4; c++) pinMode(COL_PINS[c], INPUT_PULLUP);
  for (int r = 0; r < 4; r++) pinMode(ROW_PINS[r], INPUT);
  pinMode(PIN_POT_HI, OUTPUT); digitalWrite(PIN_POT_HI, HIGH);
  analogReadResolution(12);
  analogSetPinAttenuation(PIN_POT, ADC_11db);

  i2cScan();
  if (oledOk) { oled.setBusClock(400000); oled.begin(); oled.setContrast(200); }
  else Serial.println("!! no OLED at 0x3C/0x3D - continuing without it");

  amp.setPins(PIN_AMP_BCLK, PIN_AMP_LRC, PIN_AMP_DIN);
  bool ok = amp.begin(I2S_MODE_STD, RATE, I2S_DATA_BIT_WIDTH_16BIT, I2S_SLOT_MODE_STEREO);
  Serial.printf("AMP I2S begin=%s  BCLK %d LRC %d DIN %d\n", ok ? "OK" : "FAILED", PIN_AMP_BCLK, PIN_AMP_LRC, PIN_AMP_DIN);
  xTaskCreatePinnedToCore(audioTask, "audio", 4096, NULL, 5, NULL, 0);
  noteKey = 9; delay(300); noteKey = -1;                            // boot beep
  Serial.println("Press keys (S1..S16), turn the pot.\n");
}
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
